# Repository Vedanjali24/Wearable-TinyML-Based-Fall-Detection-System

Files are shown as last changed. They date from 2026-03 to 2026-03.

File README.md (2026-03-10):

# Wearable-TinyML-Based-Fall-Detection-System
This project focuses on the design and development of a wearable health monitoring system capable of performing real-time motion analysis and fall detection directly on the device. The system is built around the ESP32 microcontroller, which serves as the main processing unit for sensor data acquisition, TinyML inference, and data logging.

The device integrates an MPU6050 inertial measurement unit (IMU) to capture motion and orientation data and a MAX30102 optical sensor for physiological monitoring such as heart rate and blood oxygen levels. Motion data from the IMU is processed locally using a TinyML model trained for fall detection, allowing the system to identify abnormal movement patterns without requiring external computation resources.

To enable reliable data storage and post-analysis, the system includes SD card logging, where raw sensor readings and detected events are stored during operation. This allows offline analysis of movement patterns, model performance evaluation, and long-term monitoring.

A key objective of the system is privacy-preserving edge intelligence. All inference and decision-making are performed directly on the embedded device, eliminating the need for continuous cloud connectivity. This reduces latency, lowers power consumption, and ensures that sensitive health data remains local to the device.

The combination of embedded machine learning, sensor fusion, and edge processing enables the device to operate as a compact and efficient health monitoring platform capable of detecting potential falls and anomalies in real time.



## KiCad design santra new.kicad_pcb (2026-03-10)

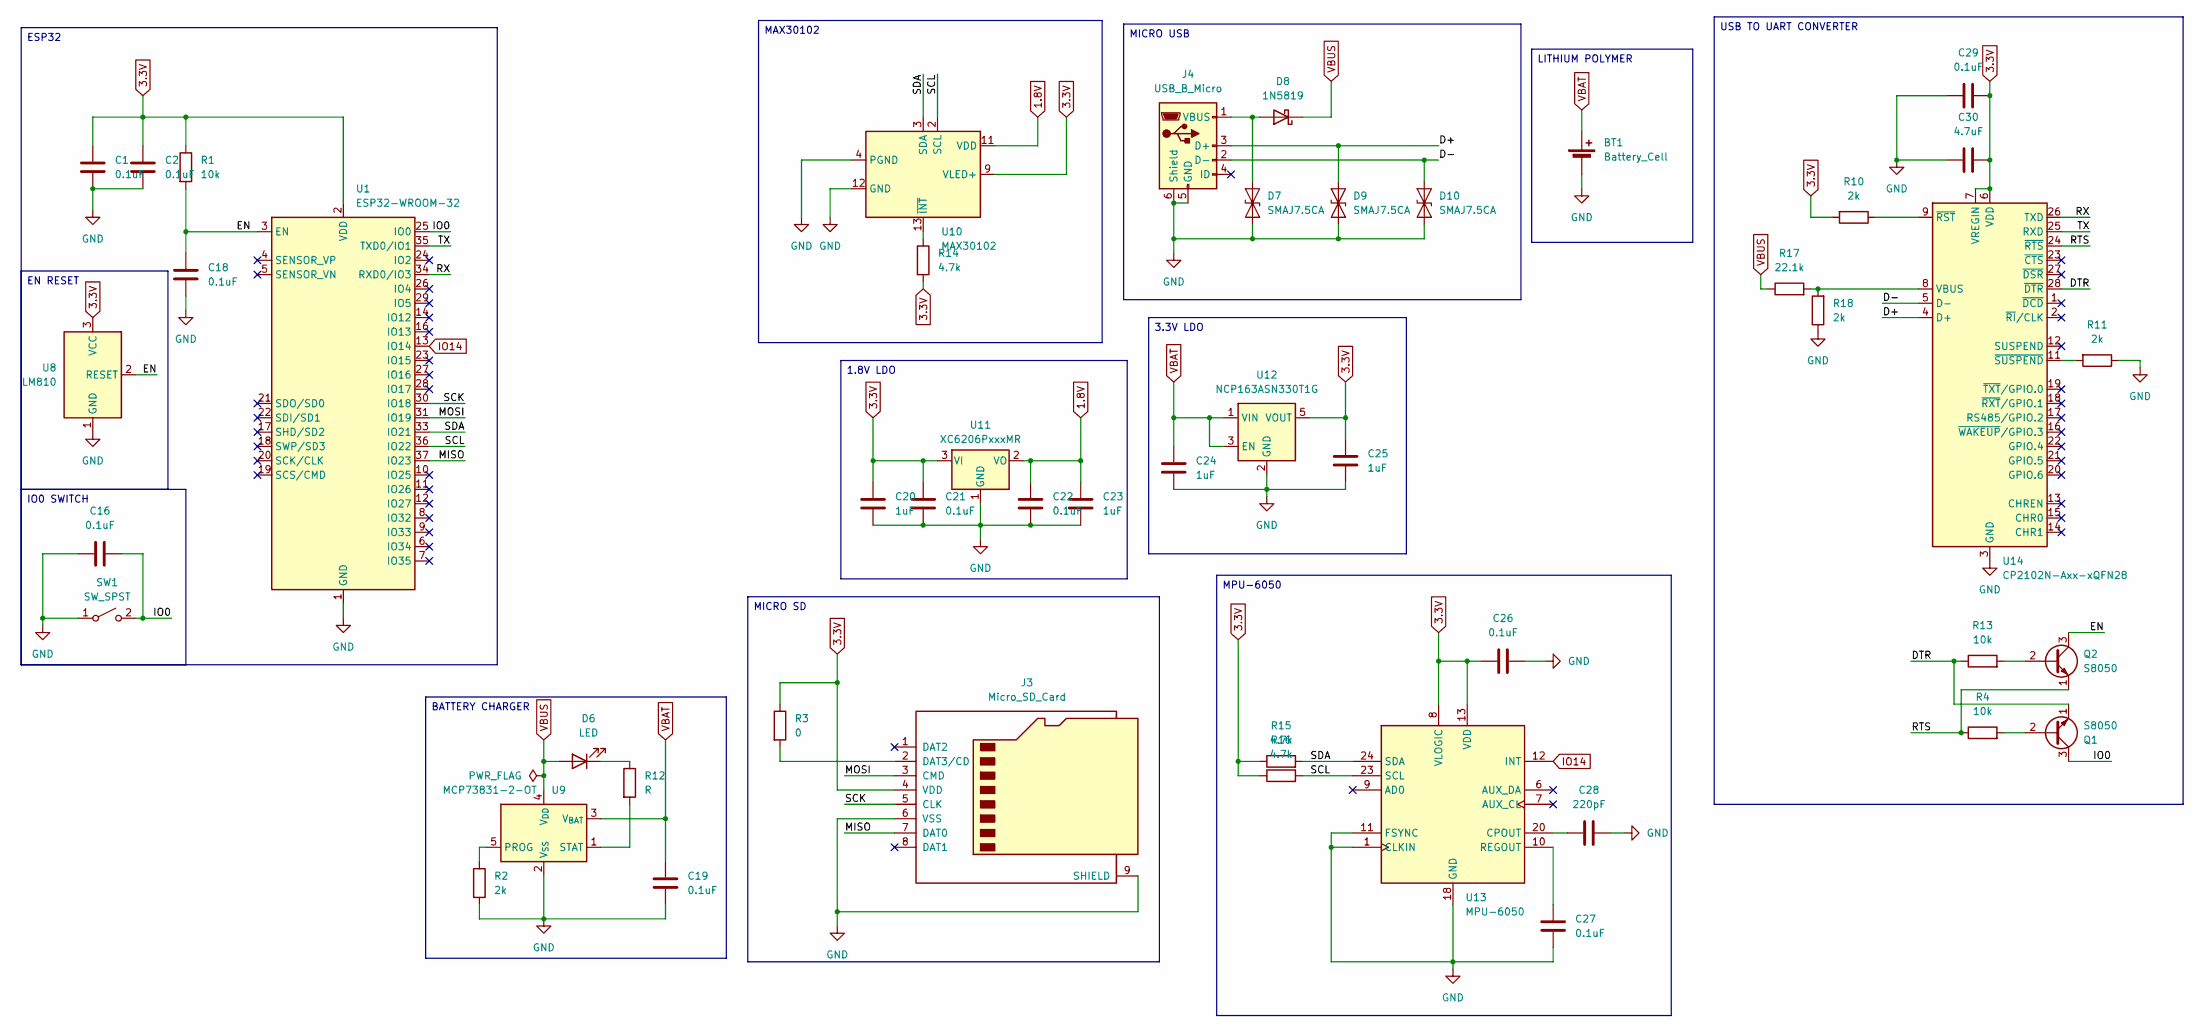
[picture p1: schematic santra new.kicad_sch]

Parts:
BT1: Battery_Cell; LED_PLCC-2_3x2mm_AK
C1, C2, C16, C18, C19, C21, C22, C26, C27, C29: 0.1uF; C_0603_1608Metric_Pad1.08x0.95mm_HandSolder
C20, C23, C24, C25: 1uF; C_0603_1608Metric_Pad1.08x0.95mm_HandSolder
C28: 220pF; C_0603_1608Metric_Pad1.08x0.95mm_HandSolder
C30: 4.7uF; C_0603_1608Metric_Pad1.08x0.95mm_HandSolder
D6: LED; LED_0603_1608Metric_Pad1.05x0.95mm_HandSolder
D7, D9, D10: SMAJ7.5CA; D_SMA
D8: 1N5819; D_DO-41_SOD81_P10.16mm_Horizontal
J3: Micro_SD_Card; microSD_HC_Molex_47219-2001
J4: USB_B_Micro; USB_Micro-B_Molex-105017-0001
Q1, Q2: S8050; Texas_DRT-3
R1, R4, R13: 10k; R_0603_1608Metric_Pad0.98x0.95mm_HandSolder
R2, R10, R11, R18: 2k; R_0603_1608Metric_Pad0.98x0.95mm_HandSolder
R3: 0; R_0603_1608Metric_Pad0.98x0.95mm_HandSolder
R12: R; R_0603_1608Metric_Pad0.98x0.95mm_HandSolder
R14, R15, R16: 4.7k; R_0603_1608Metric_Pad0.98x0.95mm_HandSolder
R17: 22.1k; R_0603_1608Metric_Pad0.98x0.95mm_HandSolder
SW1: SW_SPST; SW_Push_1P1T_NO_CK_PTS125Sx43PSMTR
U1: ESP32-WROOM-32
U8: LM810; SOT-23
U9: MCP73831-2-OT; SOT-23-5
U10: MAX30102; Maxim_OLGA-14_3.3x5.6mm_P0.8mm
U11: XC6206PxxxMR; SOT-23-3
U12: NCP163ASN330T1G; SOT-23-5
U13: MPU-6050; InvenSense_QFN-24_4x4mm_P0.5mm
U14: CP2102N-Axx-xQFN28; QFN-28-1EP_5x5mm_P0.5mm_EP3.35x3.35mm

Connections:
1.8V: C22.1, C23.1, U10.11 (VDD), U11.2 (VO)
3.3V: C1.1, C2.1, C20.1, C21.1, C25.1, C26.1, C29.2, C30.2, J3.4 (VDD), R1.1, R3.1, R10.2, R14.2, R15.1, R16.1, U1.2 (VDD), U8.3 (VCC), U10.9 (VLED+), U10.10 (VLED+), U11.3 (VI), U12.5 (VOUT), U13.8 (VLOGIC), U13.13 (VDD), U14.6 (VDD), U14.7 (VREGIN)
/D+: D9.2 (A2), J4.3 (D+), U14.4 (D+)
/D-: D10.2 (A2), J4.2 (D-), U14.5 (D-)
/DTR: Q1.1 (E), R13.1, U14.28 (~DTR)
/EN: C18.1, Q2.3 (C), R1.2, U1.3 (EN), U8.2 (RESET)
/IO0: C16.2, Q1.3 (C), SW1.2 (B), U1.25 (IO0)
/MISO: J3.7 (DAT0), U1.37 (IO23)
/MOSI: J3.3 (CMD), U1.31 (IO19)
/RTS: Q2.1 (E), R4.1, U14.24 (~RTS)
/RX: U1.34 (RXD0/IO3), U14.26 (TXD)
/SCK: J3.5 (CLK), U1.30 (IO18)
/SCL: R16.2, U1.36 (IO22), U10.2 (SCL), U13.23 (SCL)
/SDA: R15.2, U1.33 (IO21), U10.3 (SDA), U13.24 (SDA)
/TX: U1.35 (TXD0/IO1), U14.25 (RXD)
GND: BT1.2 (-), C1.2, C2.2, C16.1, C18.2, C19.2, C20.2, C21.2, C22.2, C23.2, C24.2, C25.2, C26.2, C27.2, C28.2, C29.1, C30.1, D7.1 (A1), D9.1 (A1), D10.1 (A1), J3.6 (VSS), J3.9 (SHIELD), J4.5 (GND), J4.6 (Shield), R2.2, R11.1, R18.1, SW1.1 (A), U1.1 (GND), U1.15 (GND), U1.38 (GND), U1.39 (GND), U8.1 (GND), U9.2 (V_{SS}), U10.4 (PGND), U10.12 (GND), U11.1 (GND), U12.2 (GND), U13.1 (CLKIN), U13.11 (FSYNC), U13.18 (GND), U14.3 (GND), U14.29 (GND)
IO14: U1.13 (IO14), U13.12 (INT)
unnamed: D6.1 (K), R12.1
unnamed: D7.2 (A2), D8.2 (A), J4.1 (VBUS)
unnamed: J3.2 (DAT3/CD), R3.2
unnamed: Q1.2 (B), R4.2
unnamed: Q2.2 (B), R13.2
unnamed: R2.1, U9.5 (PROG)
unnamed: R12.2, U9.1 (STAT)
unnamed: R14.1, U10.13 (~INT)
unnamed: C28.1, U13.20 (CPOUT)
unnamed: C27.1, U13.10 (REGOUT)
unnamed: R17.2, R18.2, U14.8 (VBUS)
unnamed: R10.1, U14.9 (~RST)
unnamed: R11.2, U14.11 (~SUSPEND)
VBAT: BT1.1 (+), C19.1, C24.1, U9.3 (V_{BAT}), U12.1 (VIN), U12.3 (EN)
VBUS: D6.2 (A), D8.1 (K), R17.1, U9.4 (V_{DD})

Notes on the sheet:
MICRO SD
3.3V LDO
LITHIUM POLYMER
USB TO UART CONVERTER
1.8V LDO
BATTERY CHARGER
MPU-6050
IO0 SWITCH
EN RESET
ESP32
MICRO USB
MAX30102

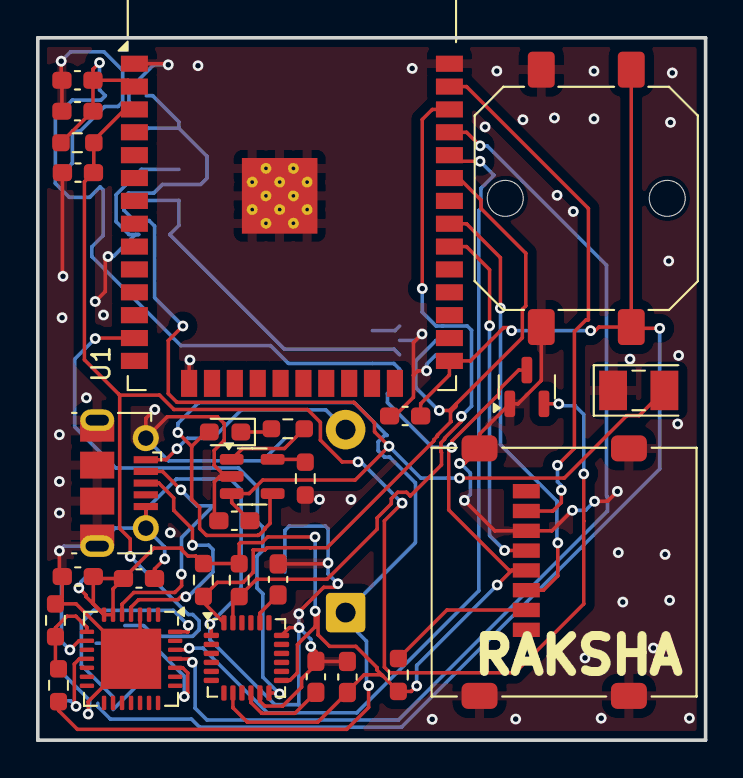
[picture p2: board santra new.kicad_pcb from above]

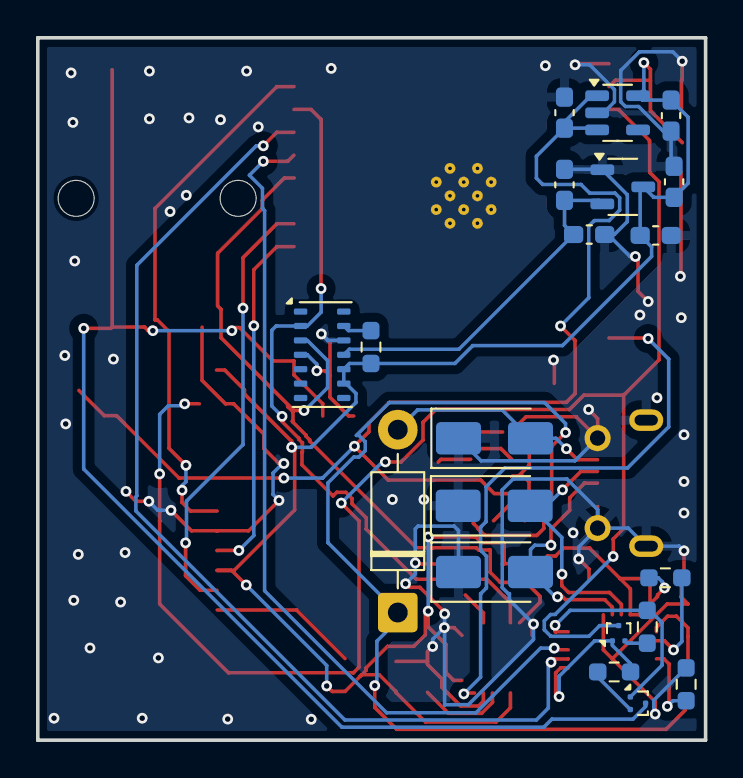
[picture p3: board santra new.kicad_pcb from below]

Board: 2 copper layers, 37.1 x 39.0 mm, 48 parts (20 on the bottom side), 32 nets.
